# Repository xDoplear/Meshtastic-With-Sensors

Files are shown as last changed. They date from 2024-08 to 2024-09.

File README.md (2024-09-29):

The included Arduino Program is designed for a Adafruit Trinket M0. If you want to use a different microcontroller, you may have to modify the code. KiCAD files for the project, schematic, and PCB are included.

# Meshtastic Heltec Sensor Config For Meshtastic App
1. Connect to the Meshtastic Radio that you want to configure. For any config import/modification, the Meshtastic device will have to restart before the config is set.
2. Press three dots on top right corner
3. Go to "Radio configuration"
4. Scroll down until you see "Import configuration" and press it
5. Import the config file named "All Sensor Final Config". This is the current configuration of the current sensor Heltecs.
   There is one called "All Sensor Final Cong" as well. This should also work but I just made a typo.
6. Go back to the "Radio configuration" and find the "Power" tab. This is where you can enable/disable power saving mode. This should be disabled in the imported configuration.
7. Under the "User" tab, change the name of the device to a fitting name. Ex: All Sensor 4
8. If you want to double check if the configuration is right or if you do not have access to the file, the following are the important settings that need to be changed
   - On the main screen, go to the gear tab on the right and make sure your region is US. You can also change your name here as well.
   - On the channels tab (the circle with a sideways wifi Logo), there should be a place to enter a URL. Enter the following URL:
     https://meshtastic.org/e/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 
     The name of the private channel should be "MendezLab"
   - The following settings will be under "Radio configuration" section
     - Go to "Device" and change the role to CLIENT_HIDDEN and enable Serial output
     - Go to "Power" and do the following. **These values may need tinkering**
         - Enable Power Saving Mode (if you see fit)
         - Change the wait for bluetooth setting to 30 seconds
         - Change both super deep sleep and light sleep duration to 300 seconds
         - Change minimum wake time to 10 seconds
      - Go to "Display" and change screen timeout to 5 seconds
      - Go to "Bluetooth" and enable bluetooth (this should already be enabled)
     - Under the "Module Configuration" go to "Serial" and do the following
         - Enable Serial
         - Enable Echo (optional)
         - Change RX pin to 18 and TX pin to 17 (change as needed, just make sure selected pins are actually UART pins or else an error will occur)
         - Change Baud rate to 9600 (this can be changed if needed, just make sure to do so in the Arduino code as well)
         - Set timeout to 1
         - Change the "Serial mode" setting to TEXTMSG

  For the Sensor Receiver Heltec, you can import the same "All Sensor Final Config" file but change the following settings:
  1. Under "Device", change role to CLIENT_MUTE
  2. Under "Serial", change baud rate to 115200

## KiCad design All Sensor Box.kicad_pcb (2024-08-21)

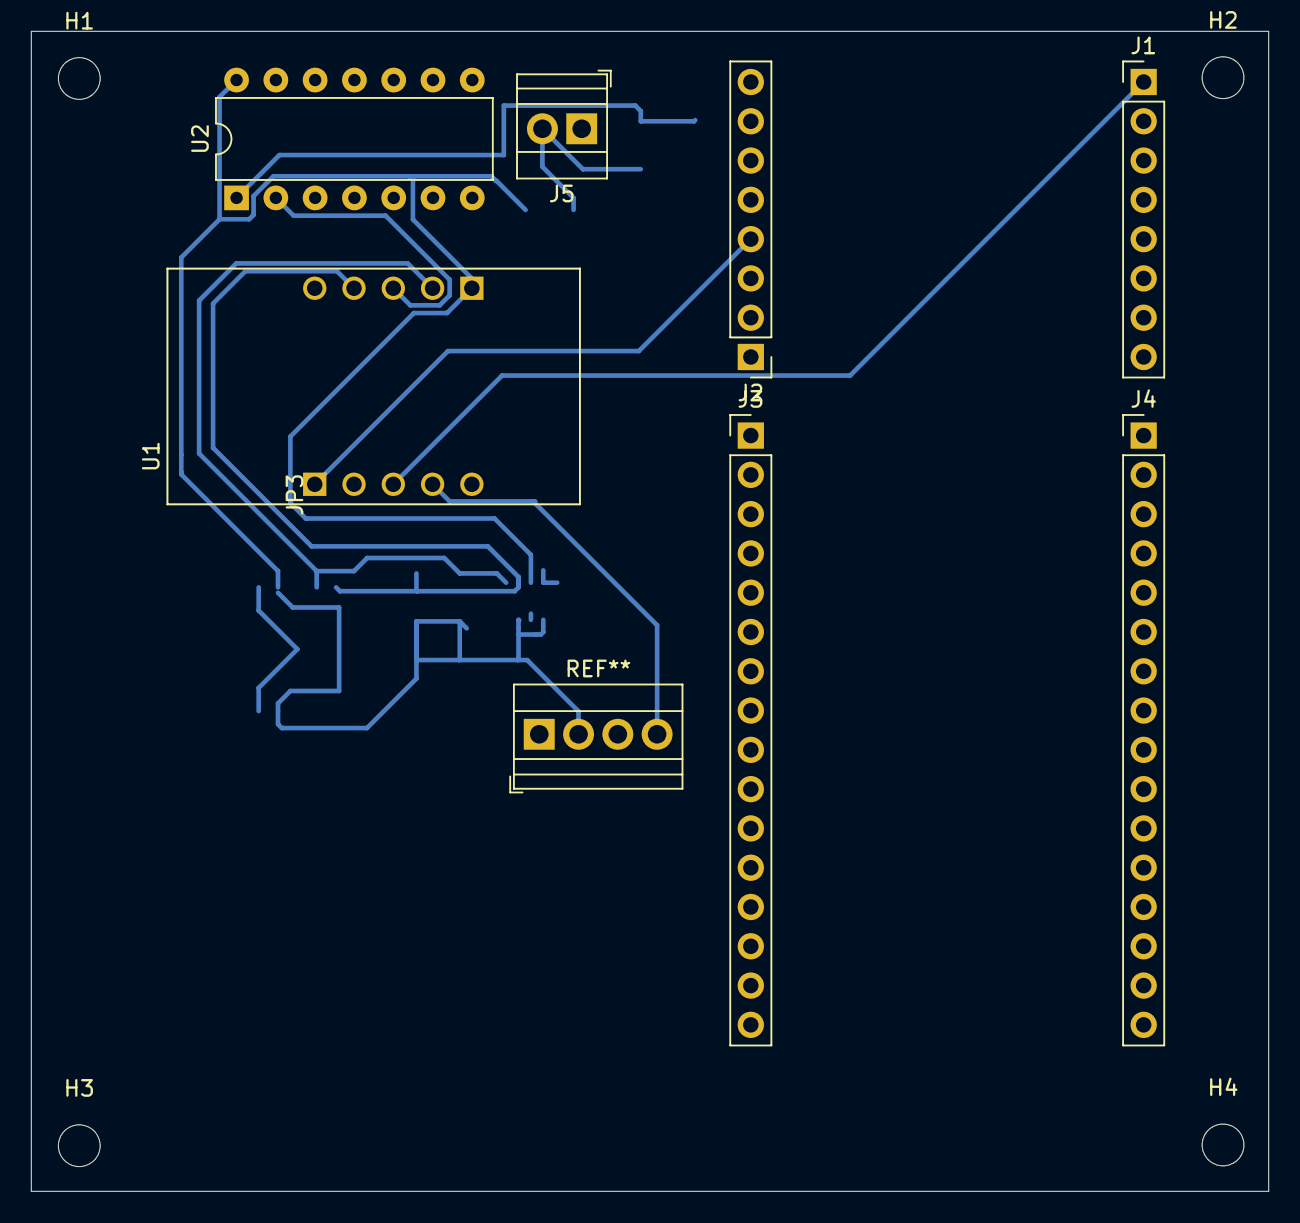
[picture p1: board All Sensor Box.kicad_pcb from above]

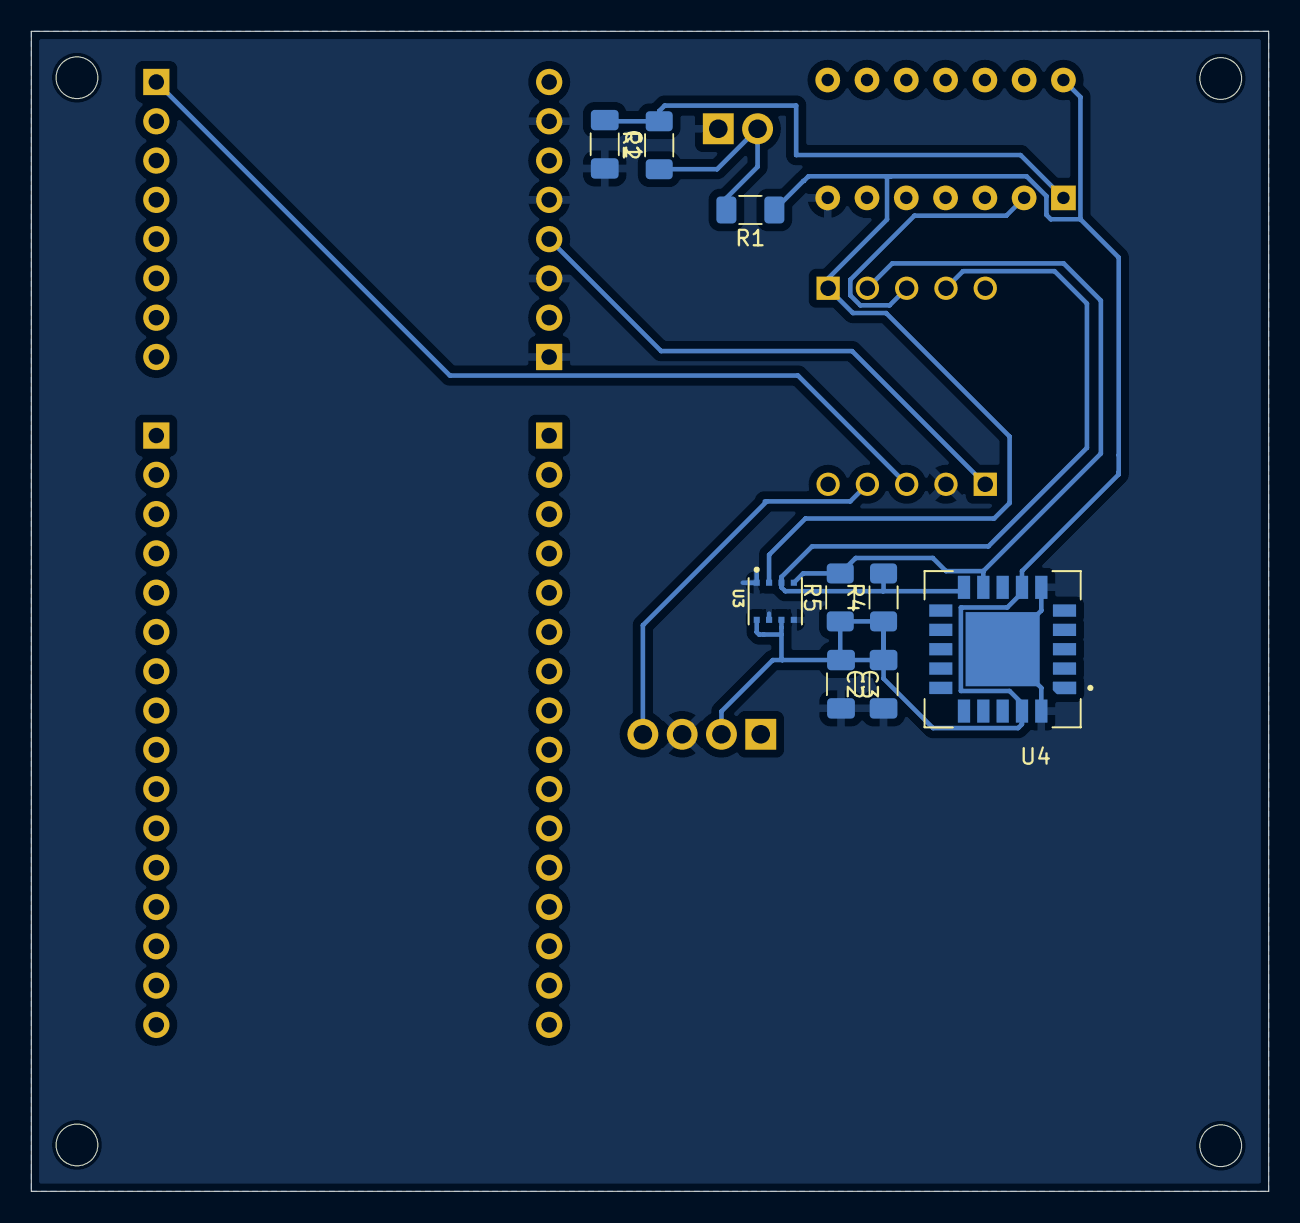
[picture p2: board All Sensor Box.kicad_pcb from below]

Board: 2 copper layers, 80.0 x 75.0 mm, 20 parts (9 on the bottom side), 9 nets.

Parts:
C1: 10uF; C_1206_3216Metric_Pad1.33x1.80mm_HandSolder
C2, C3: 100nF; C_1206_3216Metric_Pad1.33x1.80mm_HandSolder
H1, H2, H3, H4: MountingHole; MountingHole_2.7mm
J1: Conn_01x08_Pin; PinHeader_1x08_P2.54mm_Vertical
J2: Heltec Wireless Tracker v1.1; PinHeader_1x08_P2.54mm_Vertical
J3, J4: Conn_01x16_Pin; PinHeader_1x16_P2.54mm_Vertical
J5: Screw_Terminal_01x02; TerminalBlock_Xinya_XY308-2.54-2P_1x02_P2.54mm_Horizontal
R1: 10k; R_1206_3216Metric_Pad1.30x1.75mm_HandSolder
R2: 100; R_1206_3216Metric_Pad1.30x1.75mm_HandSolder
R4, R5: 4.7k; R_1206_3216Metric_Pad1.30x1.75mm_HandSolder
U1: 3500; MODULE_3500
U2: 74HC14; DIP-14_W7.62mm
U3: BME688; IC_BME688
U4: SCD41-D-R2; XDCR_SCD41-D-R2

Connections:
/3V3: C2.2, C3.1, R1.1, R4.1, R5.1, U1.JP4_1 (3.3V), U3.2 (CSB), U3.6 (VDDIO), U3.8 (VDD), U4.7 (VDD), U4.19 (VDDH)
/Bat: J2.4, U1.JP3_1 (VBAT)
/RAIN: U1.JP4_3 (D1_A0_PA02), U2.2
/RX: J1.RX (Pin_1), U1.TX (D4_A2_PA06_TXD_MOSI)
/SCL: R5.2, U1.JP4_2 (D2_A1_PA09_SCL_MISO), U3.4 (SCK), U4.9 (SCL)
/SDA: R4.2, U1.JP4_4 (D0_A4_PA08_SDA), U3.3 (SDI), U4.10 (SDA)
/SW_Power: J5.2, R1.2, R2.1
GND: C1.2, C2.1, C3.2, J2.1, J2.3, J2.5, J2.7, J5.1, U1.JP3_2 (GND), U2.7, U3.1 (GND), U3.5 (SDO), U3.7 (GND), U4.6 (GND), U4.20 (GND), U4.21 (GND)
unnamed: C1.1, R2.2, U2.1

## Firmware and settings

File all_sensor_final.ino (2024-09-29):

#include <Arduino.h>
#include <SensirionI2CScd4x.h>
#include <Wire.h>
#include "Zanshin_BME680.h"

SensirionI2CScd4x scd4x;
BME680_Class BME680;

int delayTimeMin = 1; // Sets time interval in minutes to send data
int delayTimeMilli = delayTimeMin * 60000;
unsigned long previousTime = 0;
const int RAIN_PIN = 1; // Pin for rain gauge
const int GEO_PIN = 3; // Pin for 
volatile int total = 0;
float geoSensor = 0;
bool updateSerial = false;

// Root Mean Square to get better analog values from geophone
const int numSamples = 100; // Number of samples to calculate RMS
float geoReadings[numSamples];
int sampleIndex = 0;

//Set seaLevel for altitude function below
float altitude(const int32_t press, const float seaLevel = 1013.25);

//setup function
void setup() {
  Serial.begin(9600);   //baud rate setup for serial ports
  Serial1.begin(9600, SERIAL_8N1);
  pinMode(RAIN_PIN, INPUT);   //rain pin setup
  pinMode(GEO_PIN, INPUT);  //geo pin setup

  attachInterrupt(digitalPinToInterrupt(RAIN_PIN), count, RISING);

  /*#ifdef __AVR_ATmega32U4__ //for if a board is an ATmega32U4 chip (not needed)
  delay(3000);
  #endif*/

  /*while (!Serial) { //Uncomment this to debug in serial console
      delay(100);
  }*/

  Wire.begin();

  //finds BME688 if not detected
  while (!BME680.begin(I2C_STANDARD_MODE)) {
      Serial.print(F("-  Unable to find BME688. Trying again in 5 seconds.\n"));
      delay(5000);
  }

  BME680.setOversampling(TemperatureSensor, Oversample16);
  BME680.setOversampling(HumiditySensor, Oversample16);
  BME680.setOversampling(PressureSensor, Oversample16);
  BME680.setIIRFilter(IIR4);
  BME680.setGas(320, 150);

  uint16_t error;
  char errorMessage[256];

  scd4x.begin(Wire);

  //Various error messages for SCD41 setup
  error = scd4x.stopPeriodicMeasurement();
  if (error) {
    Serial.print("Error trying to execute stopPeriodicMeasurement(): ");
    errorToString(error, errorMessage, 256);
    Serial.println(errorMessage);
  }

  uint16_t serial0, serial1, serial2;
  error = scd4x.getSerialNumber(serial0, serial1, serial2);
  if (error) {
    Serial.print("Error trying to execute getSerialNumber(): ");
    errorToString(error, errorMessage, 256);
    Serial.println(errorMessage);
  } else {
      printSerialNumber(serial0, serial1, serial2);
  }

  error = scd4x.startPeriodicMeasurement();
  if (error) {
    Serial.print("Error trying to execute startPeriodicMeasurement(): ");
    errorToString(error, errorMessage, 256);
    Serial.println(errorMessage);
  }

  Serial.println("Waiting for first measurement...");
}

//main loop function
void loop() {
  static char buf[16];
  int32_t temp, humidity, pressure, gas;
  BME680.getSensorData(temp, humidity, pressure, gas); //gets BME688 data

  uint16_t co2 = 0;
  float scd4xTemperature = 0.0f;
  float scd4xHumidity = 0.0f;
  bool isDataReady = false;
  uint16_t error;
  char errorMessage[256];
  unsigned long currentTime = millis(); //use to measure total time running
  geoSensor = (analogRead(GEO_PIN) / 1023.00) * 3.3; //convert analog pin value to voltage
  volatile int delayTime;
  
  // Store the reading and update the index
  geoReadings[sampleIndex] = geoSensor;
  sampleIndex = (sampleIndex + 1) % numSamples; // Wrap around the index

  // Calculate the RMS value
  float geoRMS = calculateRMS(geoReadings, numSamples);
  //Serial.println(geoRMS, 2); //Prints the analog data from pin 3

 if (geoRMS < 0.25) {
    delayTime = 10000; //send data every 10 seconds when geophone vibrating
  }
  else if (geoRMS > 0.25) {
    delayTime = delayTimeMilli;
  }

  //Check if SCD41 data is ready
  error = scd4x.getDataReadyFlag(isDataReady);
  if (error) {
    Serial.print("Error trying to execute getDataReadyFlag(): ");
    errorToString(error, errorMessage, 256);
    Serial.println(errorMessage);
    return;
  }

  if (!isDataReady) {
      return;
  }

  //Sends data using the user selected interval
  if (currentTime - previousTime >= delayTime) {
    previousTime = currentTime; 
    //prints all data whenever the SCD41 is ready
    if (isDataReady) {
      error = scd4x.readMeasurement(co2, scd4xTemperature, scd4xHumidity);
      if (error) {
        Serial.print("Error trying to execute readMeasurement(): ");
        errorToString(error, errorMessage, 256);
        Serial.println(errorMessage);
      } 
      else if (co2 == 0) { //invalid reading when co2 reading is 0
        Serial.println("Invalid sample detected, skipping.");
        Serial1.println("Invalid sample detected, skipping.");
      }
      else {
        //Prints SCD41 data & pressure from BME688
        Serial.println(String(scd4xTemperature) + " " + String(scd4xHumidity) + " " + String(co2)); //main serial console
        Serial1.println(String(scd4xTemperature) + " " + String(scd4xHumidity) + " " + String(co2)); //UART port

        //Prints all BME688 data 
        static float alt = altitude(pressure);
        Serial.print(String(temp / 100) + "." + String(temp % 100) + " ");            //main serial console
        Serial.print(String(humidity / 1000) + "." + String(humidity % 1000) + " ");
        Serial.print(String(pressure / 100) + "." + String(pressure % 100) + " ");
        Serial.print(String(alt, 2) + " ");
        Serial.println(String(gas  / 100) + "." + String(gas % 100));
        
        Serial1.print(String(temp / 100) + "." + String(temp % 100) + " ");           //UART serial port
        Serial1.print(String(humidity / 1000) + "." + String(humidity % 1000) + " ");
        Serial1.print(String(pressure / 100) + "." + String(pressure % 100) + " "); 
        Serial1.print(String(alt, 2) + " ");
        Serial1.println(String(gas  / 100) + "." + String(gas % 100) + " ");
      }
    }
  }
  if (updateSerial) {
    rainTotal();
    delay(10);
  }
}

//SCD41 setup stuff
void printUint16Hex(uint16_t value) {
    Serial.print(value < 4096 ? "0" : "");
    Serial.print(value < 256 ? "0" : "");
    Serial.print(value < 16 ? "0" : "");
    Serial.print(value, HEX);
}

//more SCD41 setup stuff
void printSerialNumber(uint16_t serial0, uint16_t serial1, uint16_t serial2) {
    Serial.print("Serial: 0x");
    printUint16Hex(serial0);
    printUint16Hex(serial1);
    printUint16Hex(serial2);
    Serial.println();
}

//prints rain gauge data
void rainTotal() {
  noInterrupts(); // Temporarily disable interrupts to safely read 'total'
  float currentRain = total * 0.01;
  updateSerial = false; // Reset the flag
  interrupts(); // Re-enable interrupts

  Serial.println(String(currentRain));
  Serial1.println(String(currentRain));
}

//Counts up for how many times rain gauge tips
void count() {
  total += 1;
  updateSerial = true;
}

//function to calculate altitude (may need to be modified.)
float altitude(const int32_t press, const float seaLevel) {
  static float Altitude;
  Altitude =
      44330.0 * (1.0 - pow(((float)press / 100.0) / seaLevel, 0.1903));  // Convert into meters
  return (Altitude);
}

// Function to calculate RMS of an array of float values
float calculateRMS(float* data, int numSamples) {
  float sumOfSquares = 0.0;
  
  for (int i = 0; i < numSamples; i++) {
    sumOfSquares += data[i] * data[i];
  }
  
  float meanSquare = sumOfSquares / numSamples;
  return sqrt(meanSquare);
}

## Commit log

2024-08-21 Add files via upload
    Final Arduino Code to send data from BME688 and SCD41 through serial. Code is made for Adafruit Trinket M0 but can be modified for other boards as well.
2024-08-21 Add files via upload
    Project, Schematic, and PCB files for Adafruit Trinket M0, Heltec Tracker v1.1, BME688, SCD41, circuit for rain gauge, and connections for geophone.
    [All Sensor Box.kicad_pcb, All Sensor Box.kicad_sch]
2024-08-21 Add files via upload
    All Schematic and PCB related files for Heltec Tracker V1.1, Adafruit Trinket M0, and other sensors involved.
2024-08-23 Meshtastic Radio Config.md
    Instructions for how to configure the Meshtastic Devices for the current configuration
